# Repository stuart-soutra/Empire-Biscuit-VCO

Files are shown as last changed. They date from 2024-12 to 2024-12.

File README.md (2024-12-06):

# Empire Biscuit Voltage Controlled Oscillator
## Details
The Empire Biscuit VCO is a Eurorack Compatible 16HP module implementation of Thomas Henry's VCO design (details available here: https://www.birthofasynth.com/Thomas_Henry/Pages/VCO-1.html).
The module is a single-voice VCO with inputs for CV, Hard Sync, Exp FM, Lin FM and PWM, and sine, triangle, ramp and square wave signal outputs.
The module has controls for Fine and coarse frequency control, FM attenuation and pulse width.
## Transistor Temperature Control
Because of the temperature sensitivity of the PNP transistors (Q1 and Q2) used in the voltage-to-current convertor circuit, it is imperative that these two transistors are thermally matched as closely as possible. For this reason, I have located them as closely together as possible.
When mounting these transistors, I suggest that you apply a small amount of thermal paste between the flat signifier sides of each transistors case, then encase them in epoxy resin (and maybe cover them up with heatshrink to go full belts and braces).
## Front Panel and Mechanical Design
I have included my design of the front panel of the Empire Biscuit ("Empire-Biscuit_PANEL-DESIGN_V1.svg"), that shows mounting hole location and the graphical design - feel free to use this fully or as a drilling template (these are all in .svg format - I recommend using Inkscape to open and edit these).

I constructed the front panel out of aluminium sheet with the following specifications:
- Sheet thickness = 2mm
- Width = 80.9mm (16HP)
- Height = 128mm (Eurorack standard)

The design shows lines for the width of the (recommended) slots at each corner of the module. The end points of these line correspond to the external radius points of each slot. I went with a slot drill size of M2.5.

Other clearance hole sizes:
- Input/Output Receptacles = 8mm
- Pots = 6mm
## Current Rev (Uploaded)
Rev A
## Mods Required After Rev A Testing
As I have not yet completed the changes for Rev B, please implement the following mods if you would like to build it to (fully working) Rev B specifications:
- +12V and -12V should be swapped around at the IDC header - I accidentally mirrored the main input voltages from the power supply, so please make sure that these are the correct way around!
- All 3/4" jacks (input and output) require new connections - Pin 1 (shield) should be connected to GND, and Pin 2 should be the respective positive connection for each. The use of TRRS receptacles for mono connections caused some confusion here.
- For all potentionmeters, swap connections to pin 1 amd 3 around so that each control increases with clockwise rotation instead of decreasing.

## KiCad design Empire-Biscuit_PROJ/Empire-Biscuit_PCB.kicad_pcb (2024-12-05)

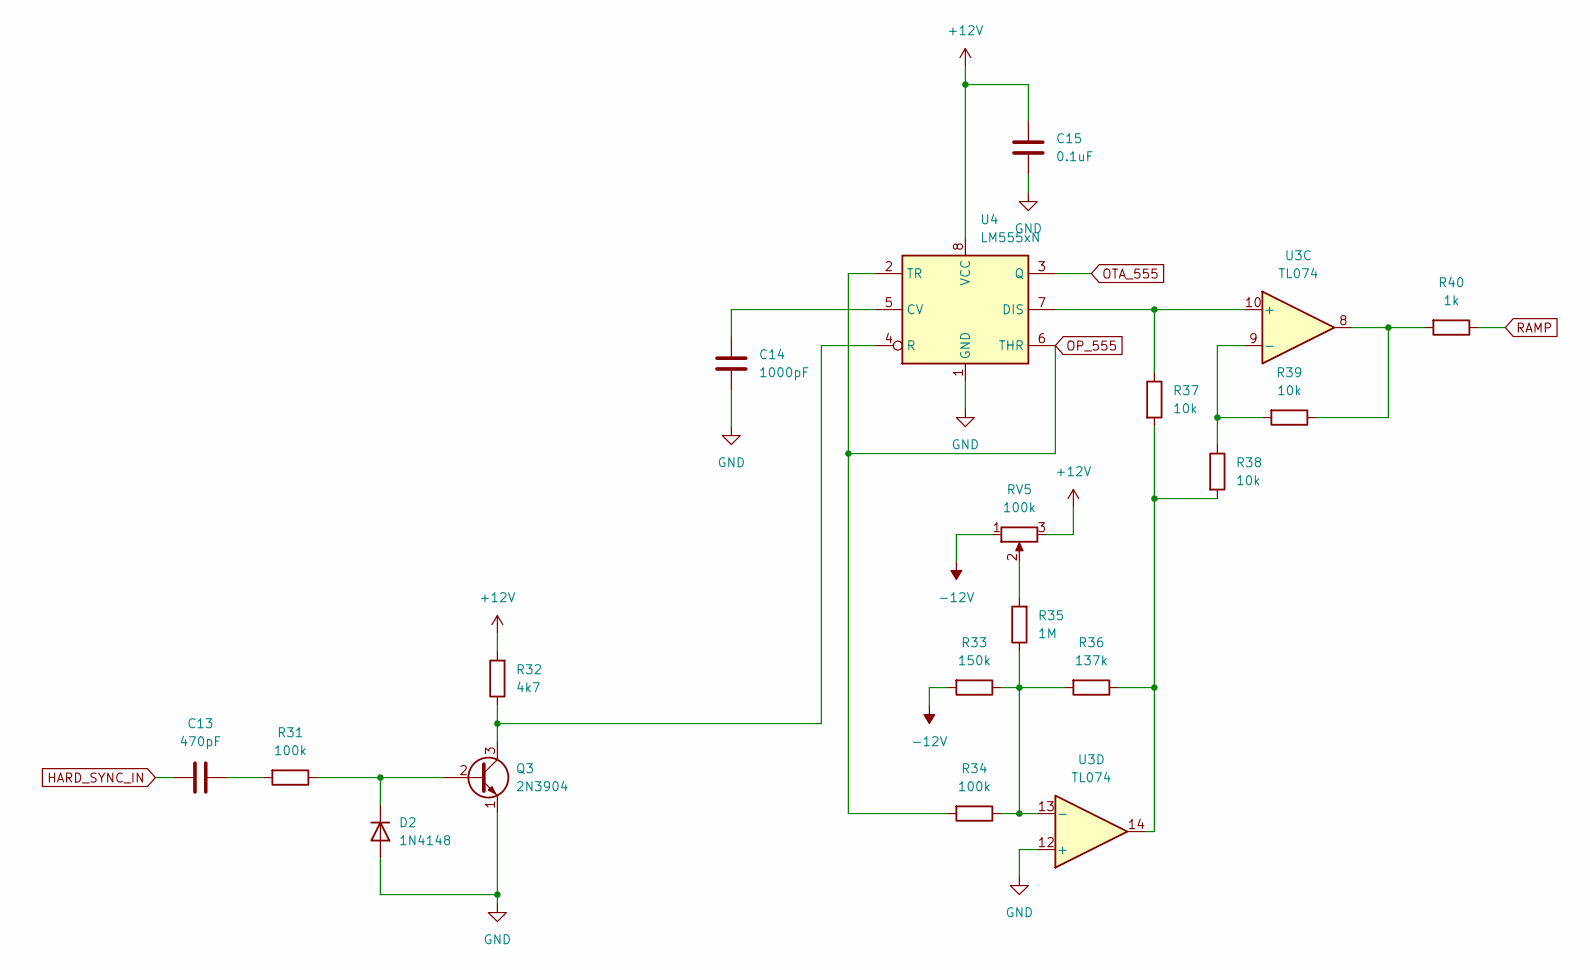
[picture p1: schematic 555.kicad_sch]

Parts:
C13: 470pF; C_0805_2012Metric_Pad1.18x1.45mm_HandSolder
C14: 1000pF; C_0805_2012Metric_Pad1.18x1.45mm_HandSolder
C15: 0.1uF; C_0805_2012Metric_Pad1.18x1.45mm_HandSolder
D2: 1N4148; D_DO-35_SOD27_P7.62mm_Horizontal
Q3: 2N3904; TO-92_Inline
R31, R34: 100k; R_0805_2012Metric_Pad1.20x1.40mm_HandSolder
R32: 4k7; R_0805_2012Metric_Pad1.20x1.40mm_HandSolder
R33: 150k; R_0805_2012Metric_Pad1.20x1.40mm_HandSolder
R35: 1M; R_0805_2012Metric_Pad1.20x1.40mm_HandSolder
R36: 137k; R_0805_2012Metric_Pad1.20x1.40mm_HandSolder
R37, R38, R39: 10k; R_0805_2012Metric_Pad1.20x1.40mm_HandSolder
R40: 1k; R_0805_2012Metric_Pad1.20x1.40mm_HandSolder
RV5: 100k; Potentiometer_Vishay_T73XW_Horizontal
U3: TL074
U4: LM555xN; DIP-8_W7.62mm

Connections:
+12V: C15.2, R32.2, RV5.3, U4.8 (VCC); also elsewhere on the board
-12V: R33.2, RV5.1; also elsewhere on the board
GND: C14.1, C15.1, D2.2 (A), Q3.1 (E), U3.12 (+), U4.1 (GND); also elsewhere on the board
HARD_SYNC_IN: C13.2; also elsewhere on the board
unnamed: C13.1, R31.2
unnamed: C14.2, U4.5 (CV)
unnamed: D2.1 (K), Q3.2 (B), R31.1
unnamed: Q3.3 (C), R32.1, U4.4 (R)
unnamed: R33.1, R34.1, R35.1, R36.2, U3.13 (-)
unnamed: R35.2, RV5.2
unnamed: R36.1, R37.2, R38.2, U3.14
unnamed: R37.1, U3.10 (+), U4.7 (DIS)
unnamed: R38.1, R39.2, U3.9 (-)
unnamed: R39.1, R40.2, U3.8
OP_555: R34.2, U4.2 (TR), U4.6 (THR); also elsewhere on the board
OTA_555: U4.3 (Q); also elsewhere on the board
RAMP: R40.1; also elsewhere on the board

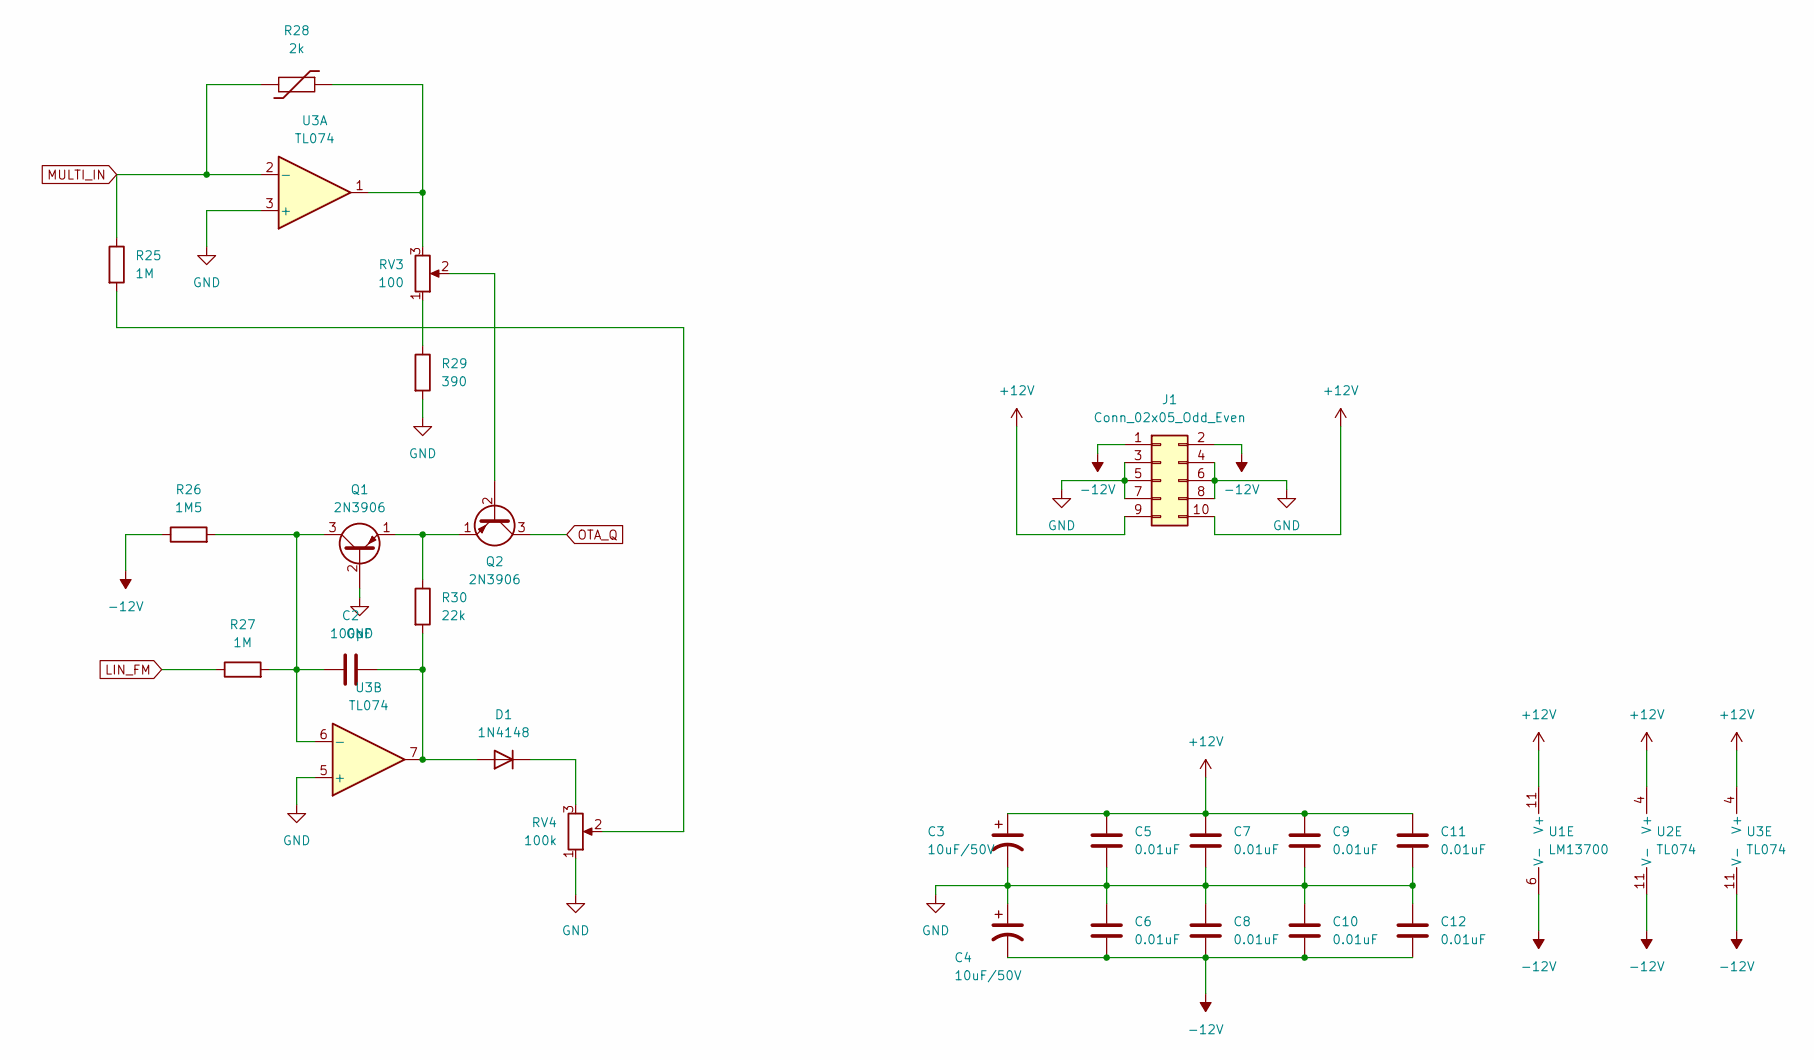
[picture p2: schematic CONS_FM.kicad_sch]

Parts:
C2: 100pF; C_0805_2012Metric_Pad1.18x1.45mm_HandSolder
C3, C4: 10uF/50V; CP_Radial_D5.0mm_P2.00mm
C5, C6, C7, C8, C9, C10, C11, C12: 0.01uF; C_0805_2012Metric_Pad1.18x1.45mm_HandSolder
D1: 1N4148; D_DO-35_SOD27_P7.62mm_Horizontal
J1: Conn_02x05_Odd_Even; PinHeader_2x05_P2.54mm_Vertical
Q1, Q2: 2N3906; TO-92_Inline
R25, R27: 1M; R_0805_2012Metric_Pad1.20x1.40mm_HandSolder
R26: 1M5; R_0805_2012Metric_Pad1.20x1.40mm_HandSolder
R28: 2k; R_Axial_DIN0204_L3.6mm_D1.6mm_P2.54mm_Vertical
R29: 390; R_0805_2012Metric_Pad1.20x1.40mm_HandSolder
R30: 22k; R_0805_2012Metric_Pad1.20x1.40mm_HandSolder
RV3: 100; Potentiometer_Vishay_T73XW_Horizontal
RV4: 100k; Potentiometer_Vishay_T73XW_Horizontal
U1: LM13700; SOIC-16_3.9x9.9mm_P1.27mm
U2: TL074; DIP-14_W7.62mm_Socket_LongPads
U3: TL074

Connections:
+12V: C3.1, C5.2, C7.2, C9.2, C11.2, J1.9, J1.10, U1.11 (V+), U2.4 (V+), U3.4 (V+); also elsewhere on the board
-12V: C4.2, C6.1, C8.1, C10.1, C12.1, J1.1, J1.2, R26.1, U1.6 (V-), U2.11 (V-), U3.11 (V-); also elsewhere on the board
GND: C3.2, C4.1, C5.1, C6.2, C7.1, C8.2, C9.1, C10.2, C11.1, C12.2, J1.3, J1.4, J1.5, J1.6, J1.7, J1.8, Q1.2 (B), R29.2, RV4.1, U3.3 (+), U3.5 (+); also elsewhere on the board
LIN_FM: R27.1; also elsewhere on the board
MULTI_IN: R25.1, R28.2, U3.2 (-); also elsewhere on the board
unnamed: C2.1, Q1.3 (C), R26.2, R27.2, U3.6 (-)
unnamed: C2.2, D1.2 (A), R30.2, U3.7
unnamed: D1.1 (K), RV4.3
unnamed: Q1.1 (E), Q2.1 (E), R30.1
unnamed: Q2.2 (B), RV3.2
unnamed: R25.2, RV4.2
unnamed: R28.1, RV3.3, U3.1
unnamed: R29.1, RV3.1
OTA_Q: Q2.3 (C); also elsewhere on the board

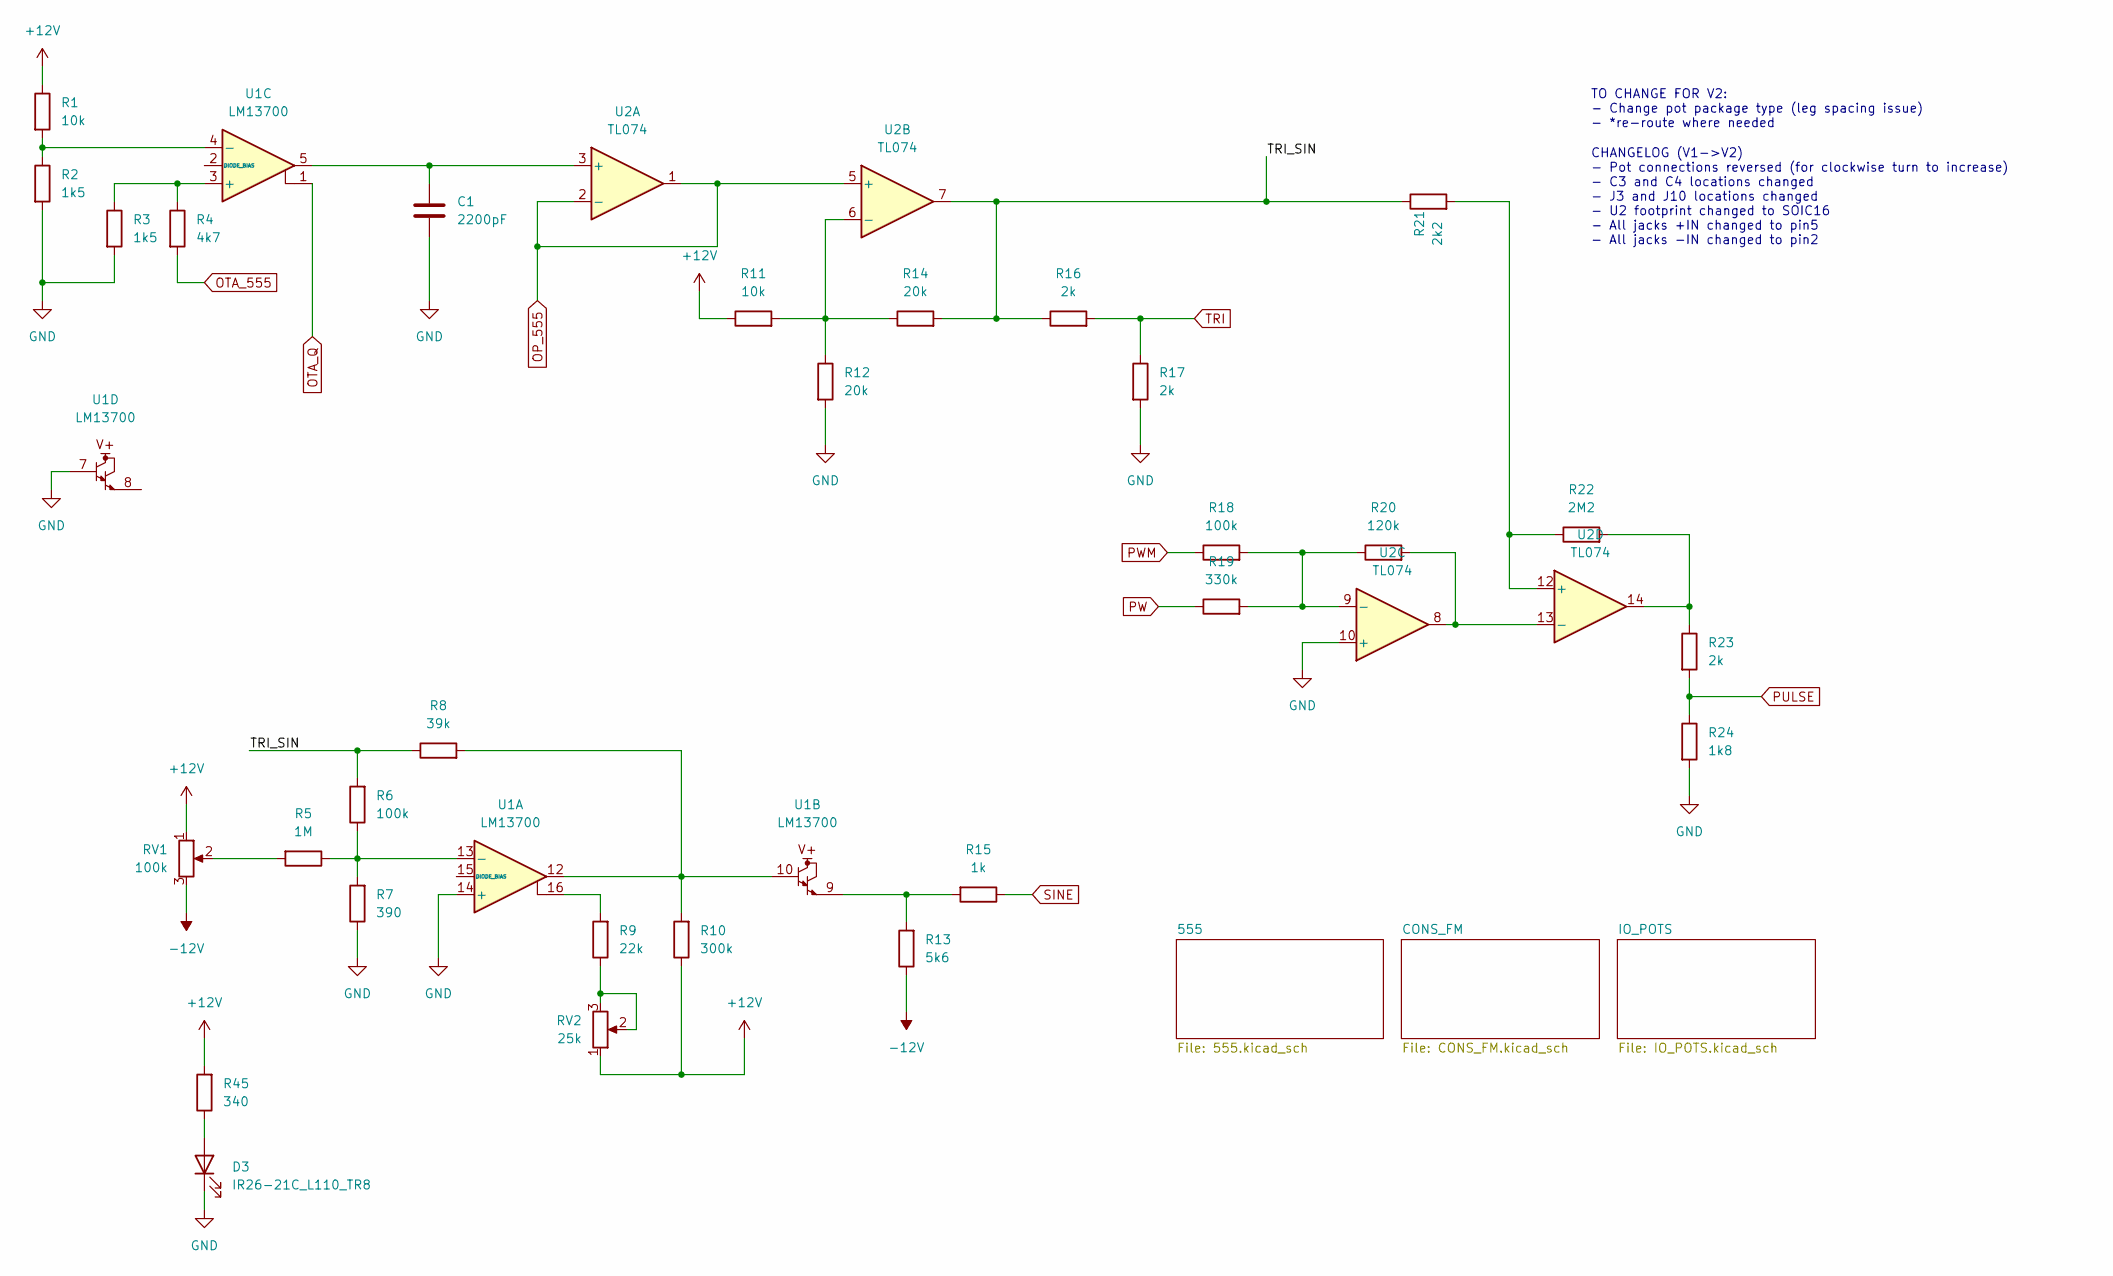
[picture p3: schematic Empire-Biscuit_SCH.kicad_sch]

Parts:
C1: 2200pF; C_0805_2012Metric_Pad1.18x1.45mm_HandSolder
D3: IR26-21C_L110_TR8; LED_1206_3216Metric
R1, R11: 10k; R_0805_2012Metric_Pad1.20x1.40mm_HandSolder
R2, R3: 1k5; R_0805_2012Metric_Pad1.20x1.40mm_HandSolder
R4: 4k7; R_0805_2012Metric_Pad1.20x1.40mm_HandSolder
R5: 1M; R_0805_2012Metric_Pad1.20x1.40mm_HandSolder
R6, R18: 100k; R_0805_2012Metric_Pad1.20x1.40mm_HandSolder
R7: 390; R_0805_2012Metric_Pad1.20x1.40mm_HandSolder
R8: 39k; R_0805_2012Metric_Pad1.20x1.40mm_HandSolder
R9: 22k; R_0805_2012Metric_Pad1.20x1.40mm_HandSolder
R10: 300k; R_0805_2012Metric_Pad1.20x1.40mm_HandSolder
R12, R14: 20k; R_0805_2012Metric_Pad1.20x1.40mm_HandSolder
R13: 5k6; R_0805_2012Metric_Pad1.20x1.40mm_HandSolder
R15: 1k; R_0805_2012Metric_Pad1.20x1.40mm_HandSolder
R16, R17, R23: 2k; R_0805_2012Metric_Pad1.20x1.40mm_HandSolder
R19: 330k; R_0805_2012Metric_Pad1.20x1.40mm_HandSolder
R20: 120k; R_0805_2012Metric_Pad1.20x1.40mm_HandSolder
R21: 2k2; R_0805_2012Metric_Pad1.20x1.40mm_HandSolder
R22: 2M2; R_0805_2012Metric_Pad1.20x1.40mm_HandSolder
R24: 1k8; R_0805_2012Metric_Pad1.20x1.40mm_HandSolder
R45: 340; R_0805_2012Metric_Pad1.20x1.40mm_HandSolder
RV1: 100k; Potentiometer_Vishay_T73XW_Horizontal
RV2: 25k; Potentiometer_Vishay_T73XW_Horizontal
U1: LM13700; SOIC-16_3.9x9.9mm_P1.27mm
U2: TL074; DIP-14_W7.62mm_Socket_LongPads

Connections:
+12V: R1.1, R10.1, R11.1, R45.2, RV1.1, RV2.1; also elsewhere on the board
-12V: R13.1, RV1.3; also elsewhere on the board
/TRI_SIN: R6.2, R8.1, R14.2, R16.1, R21.1, U2.7
GND: C1.2, D3.1 (K), R2.2, R3.2, R7.1, R12.2, R17.2, R24.2, U1.7, U1.14 (+), U2.10 (+); also elsewhere on the board
unnamed: C1.1, U1.5, U2.3 (+)
unnamed: D3.2 (A), R45.1
unnamed: R1.2, R2.1, U1.4 (-)
unnamed: R3.1, R4.1, U1.3 (+)
unnamed: R5.1, R6.1, R7.2, U1.13 (-)
unnamed: R5.2, RV1.2
unnamed: R9.1, RV2.2, RV2.3
unnamed: R9.2, U1.16
unnamed: R8.2, R10.2, U1.10, U1.12
unnamed: R11.2, R12.1, R14.1, U2.6 (-)
unnamed: R13.2, R15.2, U1.9
unnamed: R18.2, R19.2, R20.1, U2.9 (-)
unnamed: R20.2, U2.8, U2.13 (-)
unnamed: R21.2, R22.1, U2.12 (+)
unnamed: R22.2, R23.1, U2.14
OP_555: U2.1, U2.2 (-), U2.5 (+); also elsewhere on the board
OTA_555: R4.2; also elsewhere on the board
OTA_Q: U1.1; also elsewhere on the board
PULSE: R23.2, R24.1; also elsewhere on the board
PW: R19.1; also elsewhere on the board
PWM: R18.1; also elsewhere on the board
SINE: R15.1; also elsewhere on the board
TRI: R16.2, R17.1; also elsewhere on the board

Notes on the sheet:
CHANGELOG (V1->V2) - Pot connections reversed (for clockwise turn to increase) - C3 and C4 locations changed - J3 and J10 locations changed - U2 footprint changed to SOIC16 - All jacks +IN changed to pin5 - All jacks -IN changed to pin2
TO CHANGE FOR V2: - Change pot package type (leg spacing issue) - *re-route where needed

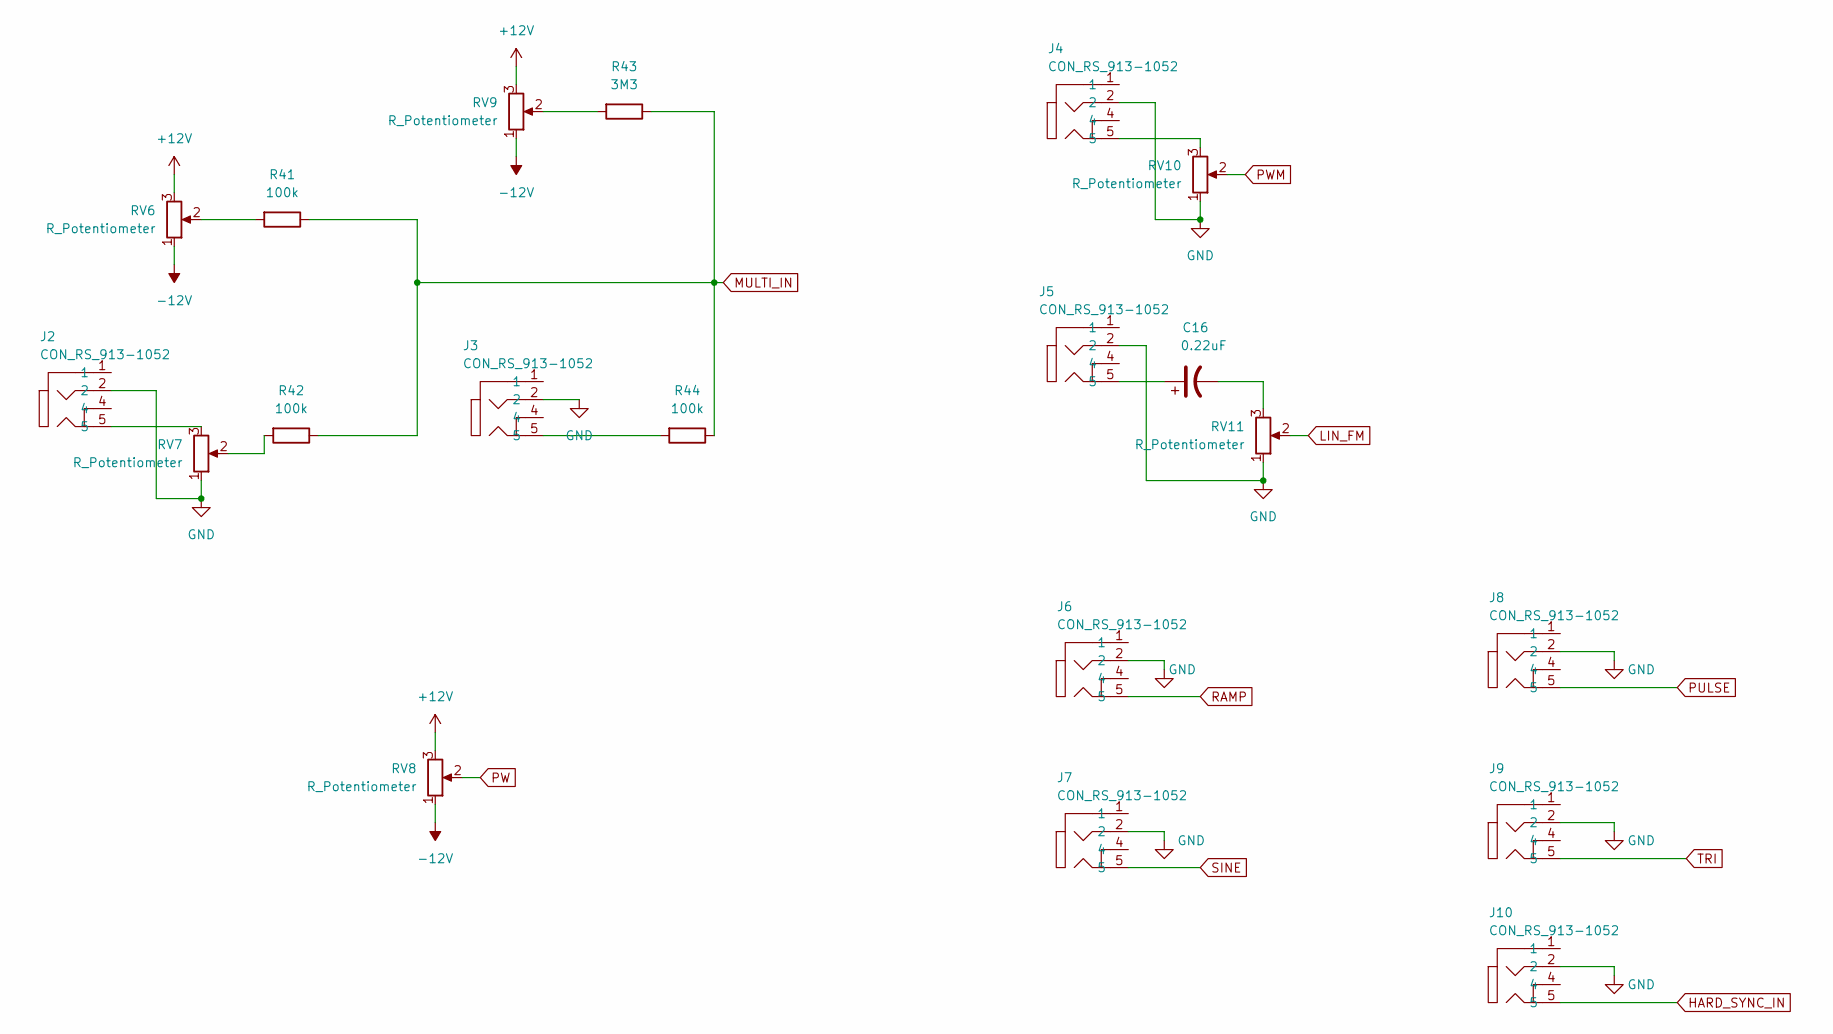
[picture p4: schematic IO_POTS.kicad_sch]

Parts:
C16: 0.22uF; CP_Radial_D5.0mm_P2.00mm
J2, J3, J4, J5, J6, J7, J8, J9, J10: CON_RS_913-1052
R41, R42, R44: 100k; R_0805_2012Metric_Pad1.20x1.40mm_HandSolder
R43: 3M3; R_0805_2012Metric_Pad1.20x1.40mm_HandSolder
RV6, RV7, RV8, RV9, RV10, RV11: R_Potentiometer; Potentiometer_Alps_RK09K_Single_Vertical

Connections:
+12V: RV6.3, RV8.3, RV9.3; also elsewhere on the board
-12V: RV6.1, RV8.1, RV9.1; also elsewhere on the board
GND: J2.2, J3.2, J4.2, J5.2, J6.2, J7.2, J8.2, J9.2, J10.2, RV7.1, RV10.1, RV11.1; also elsewhere on the board
HARD_SYNC_IN: J10.5; also elsewhere on the board
LIN_FM: RV11.2; also elsewhere on the board
MULTI_IN: R41.1, R42.1, R43.1, R44.1; also elsewhere on the board
unnamed: C16.1, J5.5
unnamed: C16.2, RV11.3
unnamed: J2.5, RV7.3
unnamed: J3.5, R44.2
unnamed: J4.5, RV10.3
unnamed: R41.2, RV6.2
unnamed: R42.2, RV7.2
unnamed: R43.2, RV9.2
PULSE: J8.5; also elsewhere on the board
PW: RV8.2; also elsewhere on the board
PWM: RV10.2; also elsewhere on the board
RAMP: J6.5; also elsewhere on the board
SINE: J7.5; also elsewhere on the board
TRI: J9.5; also elsewhere on the board

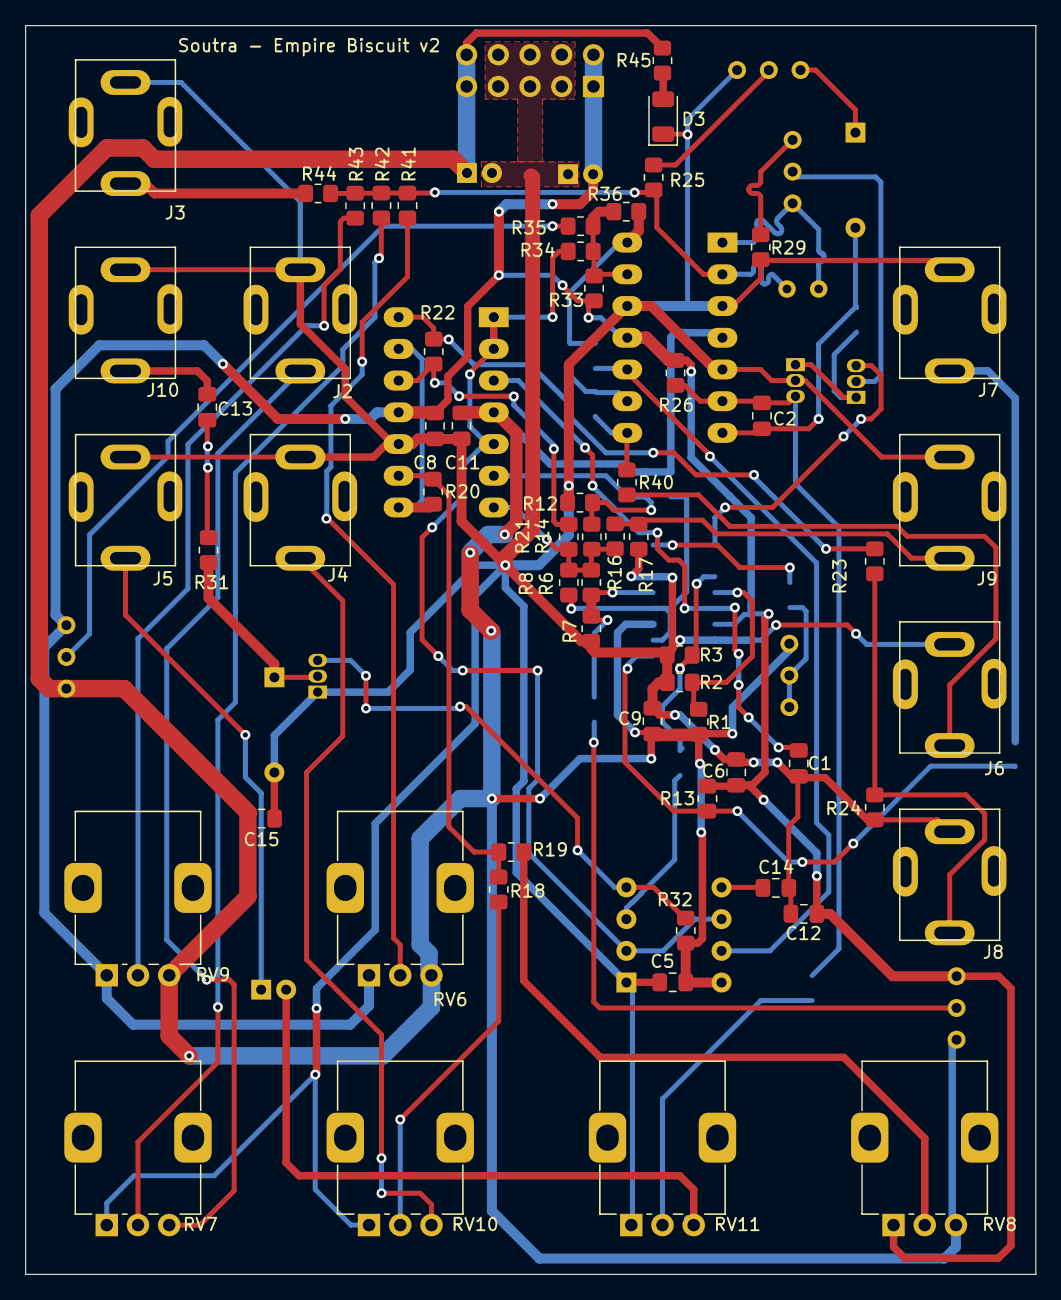
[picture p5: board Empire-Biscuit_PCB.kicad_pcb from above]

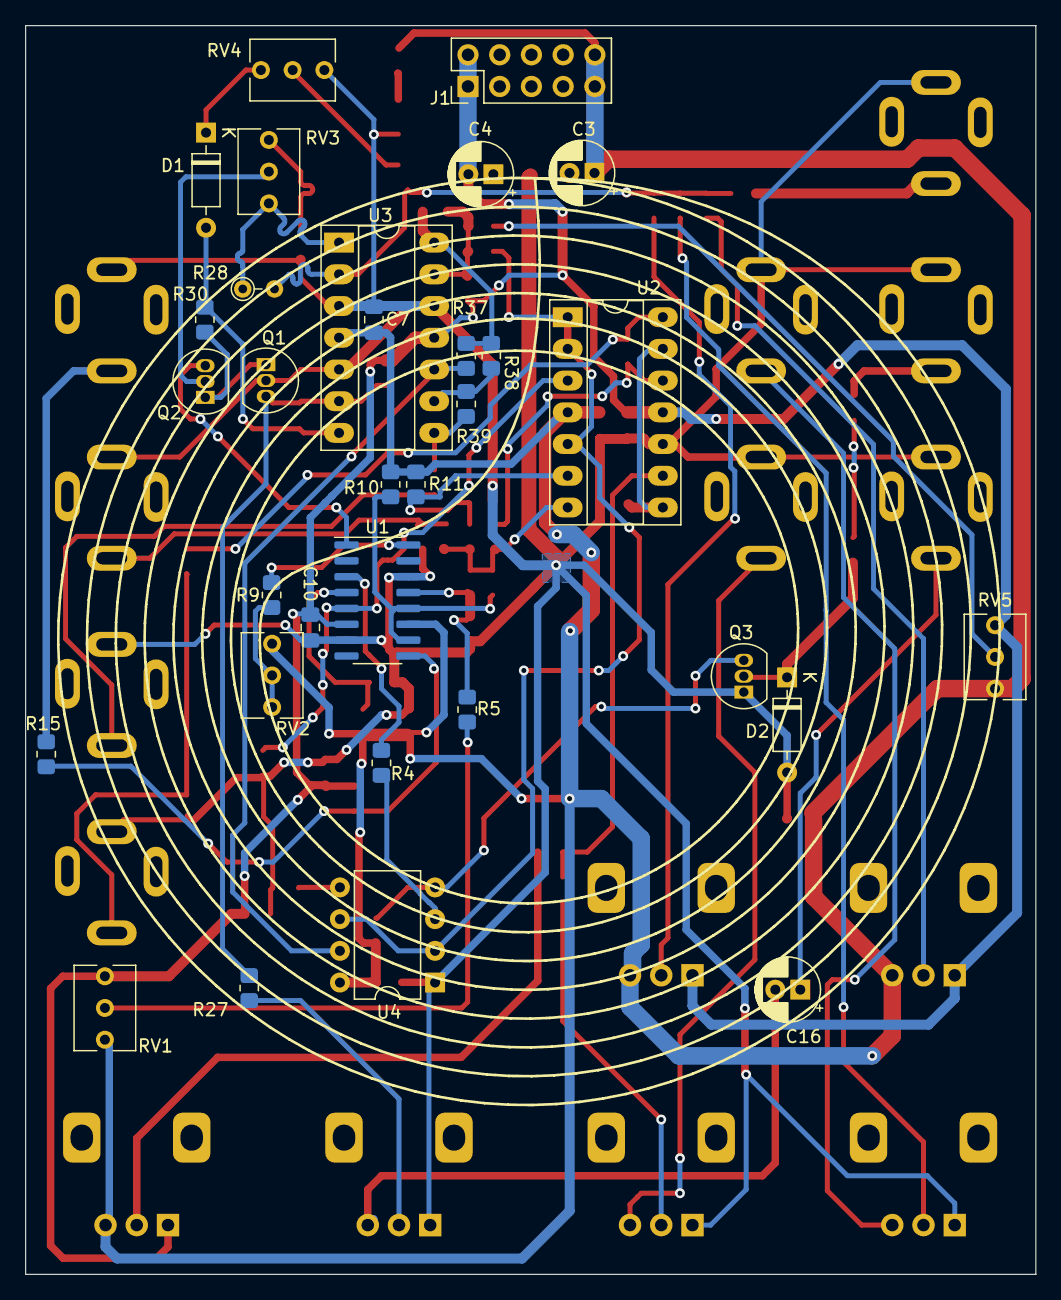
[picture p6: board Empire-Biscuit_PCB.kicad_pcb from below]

Board: 2 copper layers, 80.9 x 100.0 mm, 92 parts (32 on the bottom side), 57 nets.
